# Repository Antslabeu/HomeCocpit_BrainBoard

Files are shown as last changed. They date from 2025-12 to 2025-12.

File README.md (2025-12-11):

# BrainBoard – STM32G0 CAN-FD Base Board

BrainBoard is a small base board built around an STM32G0B1KET6 MCU and a CAN-FD transceiver.
It is intended as a “brain” for various cockpit / IO modules, providing 3V3 power, CAN-FD
communication and a common expansion interface.

Repo: https://github.com/Antslabeu/HomeCocpit_BrainBoard  

> **Status:** prototype / WIP – use at your own risk.

---

## Main Features

- MCU: **STM32G0B1KET6**
  - CAN-FD, SPI, I²C, UART, timers/PWM, ADC, GPIO exposed on board connectors
- CAN-FD transceiver: **MCP2542FDxMF**
- Power architecture:
  - Input: **12 V**
  - On-board DC/DC step-down (2× **TPS62170DSG**):
    - **3.3 V / 1 A** rail for MCU and logic
    - **5 V** rail available on board
- PCB:
  - **4-layer** board, 1.6 mm
  - Stackup: **JLC04161H-7628** (JLCPCB)

---

## Programming Connector – `STM_PROG` (J1)

6-pin programming/debug connector for SWD + UART:

| Pin | Signal | Net | Description |
|-----|---|---|---|
| 1 | VCC | 3.3V | Target supply (3.3 V) |
| 2 | DIO | SW_DIO | SWD data I/O |
| 3 | RST | SW_RST | MCU reset (NRST) |
| 4 | CLK | SW_CLK | SWD clock |
| 5 | TX | SW_TX  | MCU UART TX (debug / bootloader)|
| 6 | GND | GND | Ground |

Compatible with ST-Link, J-Link and other SWD programmers.

---

## IO Connectors (Module Interface)

The board exposes module connectors that carry:

- **SPI bus** (shared)
- **4× chip select (CS) lines**
- **UART**
- **2× PWM outputs**
- **4× ADC inputs**
- **I²C bus** with **4.7 kΩ pull-ups** to 3.3 V
- **4× IO Board ID lines** – used to identify the type of module plugged into the connector  
  *(this Board ID mechanism is WIP and may change)*

Exact pinout is defined in the KiCad schematics (`connectors.kicad_sch`).

---

## CAN-FD Bus

- Transceiver: **MCP2542FDxMF** (CAN 2.0 / CAN FD up to 8 Mbit/s).
- CANH / CANL (and GND / power, if needed) are routed to dedicated connectors.
- Standard **120 Ω termination** is intended **only at the ends of the main bus**
  (check schematic for jumpers / solder bridges).

---

## Power

- **Input:** nominal **12 V**
- **Converters:** 2× **TPS62170DSG** buck regulators  
  (3 V–17 V in, up to 0.5 A each)  [Texas Instruments](https://www.ti.com/lit/ds/symlink/tps62170.pdf?utm_source=chatgpt.com)
- **Outputs:**
  - 12 V → **3.3 V / 1 A**
  - 12 V → **5 V** (aux rail)

### Typical consumption (board only, no external loads – rough estimate)

- STM32G0B1 in Run mode @ 64 MHz: typ. ~8–9 mA @ 3.3 V  [STMicroelectronics](https://www.st.com/resource/en/datasheet/stm32g0b1cc.pdf?utm_source=chatgpt.com)
- MCP2542FD supply current:
  - recessive: typ. ~2.5–5 mA @ 5 V
  - dominant: typ. ~55–70 mA @ 5 V  [DigiKey](https://www.digikey.kr/htmldatasheets/production/1897584/0/0/1/mcp2542-44fd-wfd.html?utm_source=chatgpt.com)
- TPS62170 quiescent current: ~17 µA from VIN each  [Texas Instruments](https://www.ti.com/lit/ds/symlink/tps62170.pdf?utm_source=chatgpt.com)

So, approximately:

- **Idle bus (recessive):**  
  - P_out ≈ 30 mW (MCU) + 25 mW (CAN) ≈ 55 mW  
  - With ~85% efficiency, input power ≈ 65 mW → **I_in ≈ 5–6 mA @ 12 V**
- **Worst-case dominant transmit:**  
  - P_out ≈ 30 mW (MCU) + 350 mW (CAN) ≈ 380 mW  
  - Input ≈ 450 mW → **I_in ≈ 35–40 mA @ 12 V**

Real current will be higher once external modules load 3.3 V rail.

Always respect absolute maximum ratings from datasheets.

---

## Files and Tools

All hardware files are in the repo root:

- `BrainBoard.kicad_pro` – main KiCad 8 project
- `BrainBoard.kicad_sch` + hierarchical sheets:
  - `power.kicad_sch`
  - `mcu.kicad_sch`
  - `can.kicad_sch`
  - `connectors.kicad_sch`
- `BrainBoard.kicad_pcb` – PCB layout (4-layer, JLC04161H-7628)
- `BrainBoard.pdf` – schematic PDF
- `LICENSE` – MIT

**CAD tool:** KiCad **8.x** (designed with 8.0.4).

---

## Getting Started (Hardware)

1. **Open the project**  
   Clone the repo and open `BrainBoard.kicad_pro` in KiCad 8.x.

2. **Review schematics and layout**  
   Check power, CAN and connector pinouts before manufacturing.

3. **Manufacturing**  
   - Generate Gerbers from KiCad.
   - Use the **JLC04161H-7628** 4-layer stackup if ordering from JLCPCB.

4. **First power-up**  
   - Apply **12 V** to the main power input.  
   - Verify 3.3 V and 5 V rails on test points.  
   - Connect a SWD programmer to **STM_PROG** and flash a simple test firmware
     (blink + CAN init).

5. **Integrate into CAN-FD network**  
   - Connect CANH/CANL to your main CAN-FD backbone.  
   - Enable 120 Ω termination only on physical bus ends.

---

## Firmware / Software

Firmware, examples and Board ID handling are **WIP** and not yet part of this repository.

Planned:

- Reference firmware for:
  - CAN-FD communication
  - SPI-based module control
  - Board ID-based module detection

---

## License

This hardware design is released under the **MIT License**  
(see the `LICENSE` file in the repository).

---

## Disclaimer

This is a prototype board.  
No guarantees are given – **use at your own risk**, especially in any safety-critical context.

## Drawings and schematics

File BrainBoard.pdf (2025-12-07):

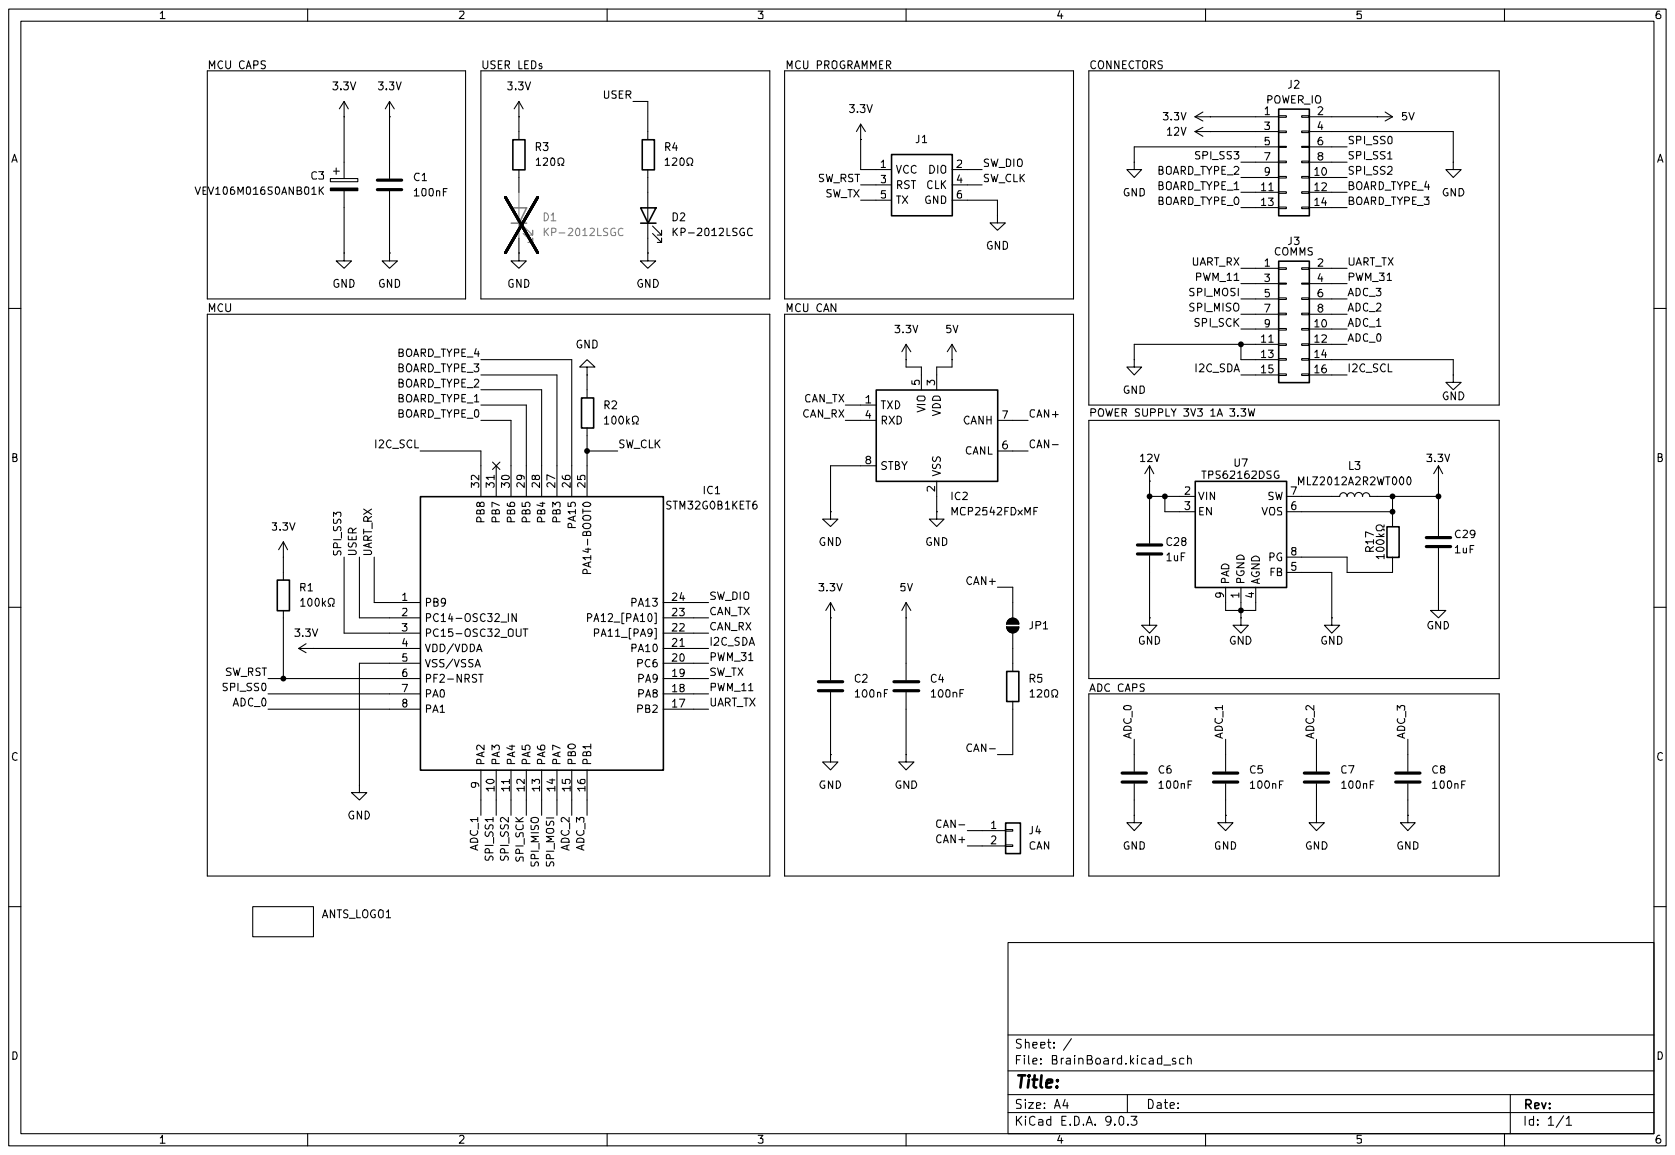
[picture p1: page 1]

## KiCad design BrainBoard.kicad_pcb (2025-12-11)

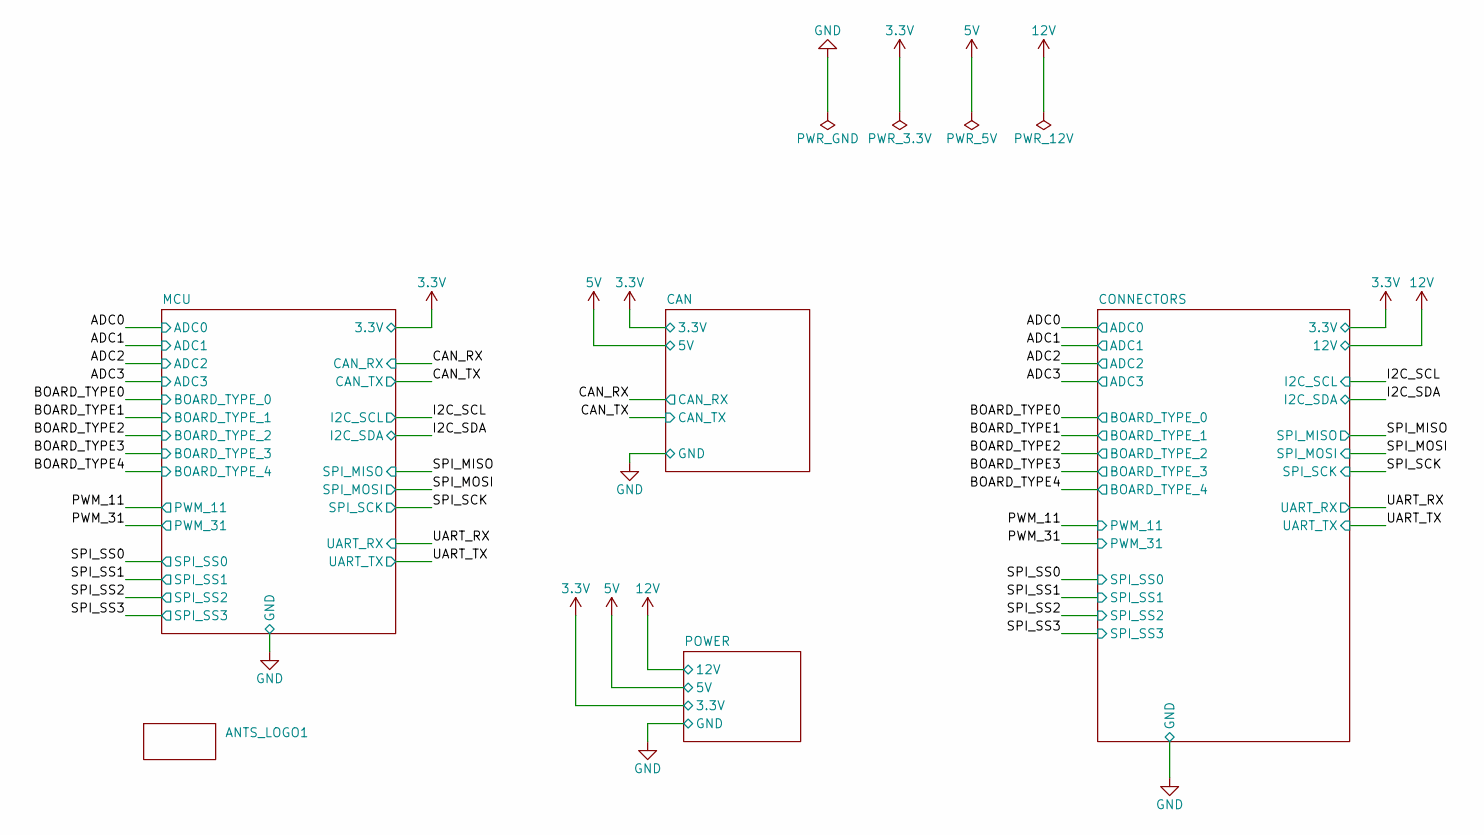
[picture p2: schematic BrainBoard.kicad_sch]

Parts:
ANTS_LOGO1: LOGO_H4

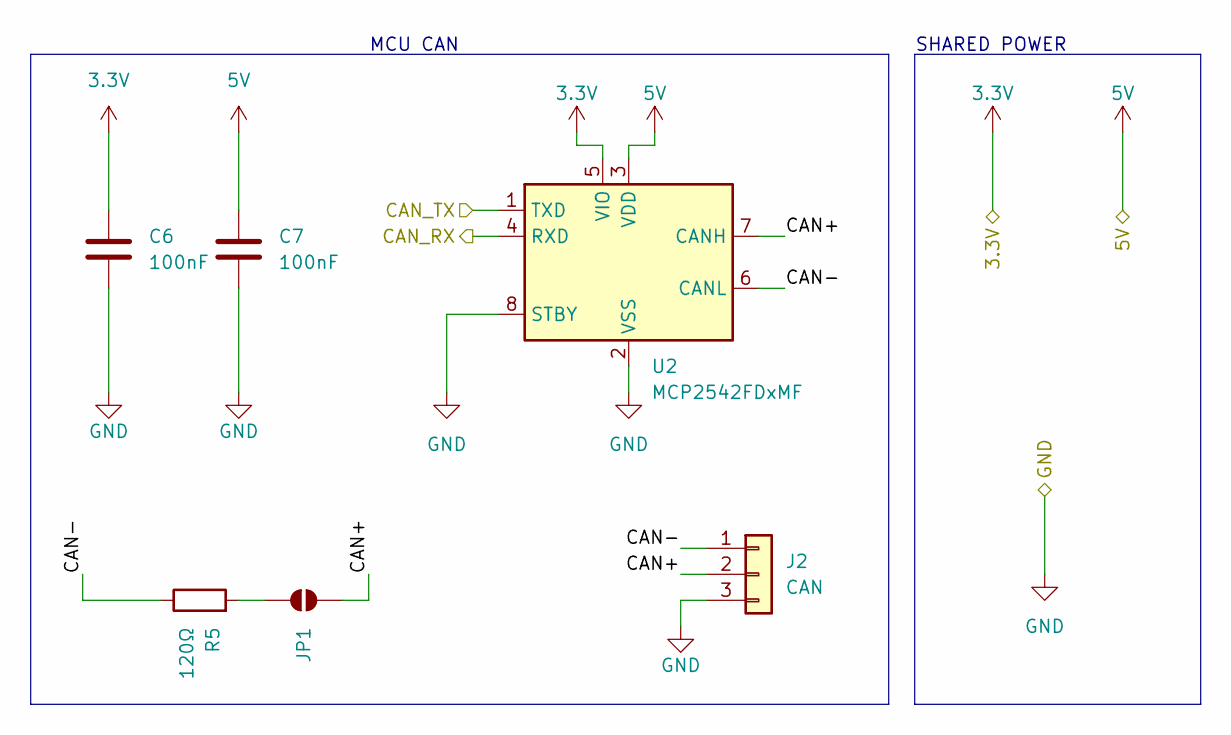
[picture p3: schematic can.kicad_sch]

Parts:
C6, C7: 100nF; C_0805_2012Metric
J2: CAN; JST_GH_BM03B-GHS-TBT_1x03-1MP_P1.25mm_Vertical
JP1: SolderJumper_2_Open; SolderJumper-2_P1.3mm_Open_RoundedPad1.0x1.5mm
R5: 120Ω; R_0805_2012Metric
U2: MCP2542FDxMF; SOIC-8_NO_PAD

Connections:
3.3V: C6.1, U2.5 (VIO); also elsewhere on the board
5V: C7.1, U2.3 (VDD); also elsewhere on the board
/CAN/CAN+: J2.2, JP1.2 (B), U2.7 (CANH)
/CAN/CAN-: J2.1, R5.1, U2.6 (CANL)
/CAN_RX: U2.4 (RXD); also elsewhere on the board
/CAN_TX: U2.1 (TXD); also elsewhere on the board
GND: C6.2, C7.2, J2.3, U2.2 (VSS), U2.8 (STBY); also elsewhere on the board
unnamed: JP1.1 (A), R5.2

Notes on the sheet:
SHARED POWER
MCU CAN

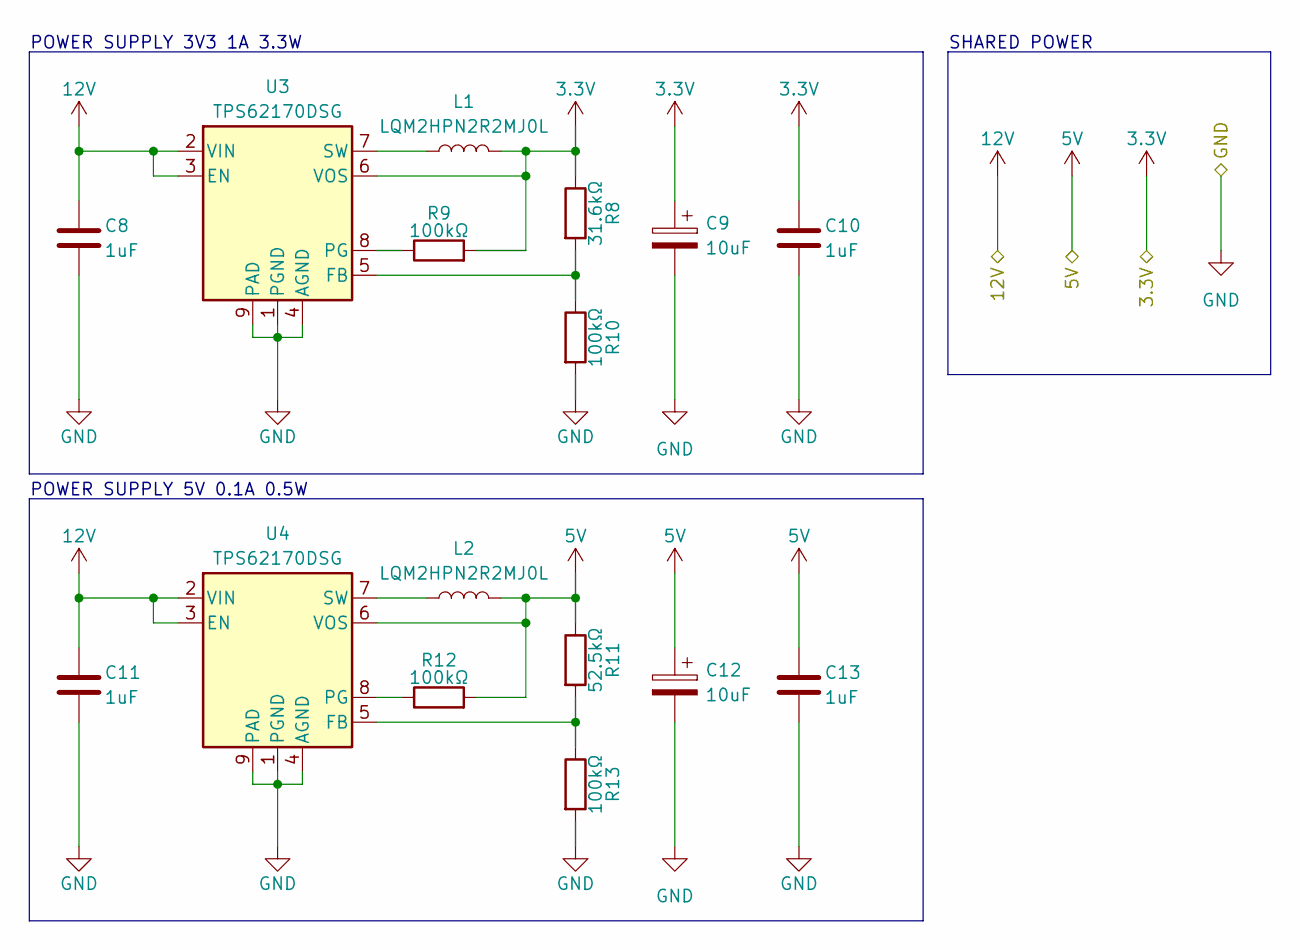
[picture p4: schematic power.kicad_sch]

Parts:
C8, C10, C11, C13: 1uF; C_0805_2012Metric
C9, C12: 10uF; CP_Elec_4x5.4
L1, L2: LQM2HPN2R2MJ0L; L_1008_2520Metric
R8: 31.6kΩ; R_0805_2012Metric
R9, R10, R12, R13: 100kΩ; R_0805_2012Metric
R11: 52.5kΩ; R_0805_2012Metric
U3, U4: TPS62170DSG; WSON-8-1EP_2x2mm_P0.5mm_EP0.9x1.6mm

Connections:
3.3V: C9.1, C10.1, L1.2, R8.1, R9.2, U3.6 (VOS); also elsewhere on the board
5V: C12.1, C13.1, L2.2, R11.1, R12.2, U4.6 (VOS); also elsewhere on the board
12V: C8.1, C11.1, U3.2 (VIN), U3.3 (EN), U4.2 (VIN), U4.3 (EN); also elsewhere on the board
GND: C8.2, C9.2, C10.2, C11.2, C12.2, C13.2, R10.2, R13.2, U3.1 (PGND), U3.4 (AGND), U3.9 (PAD), U4.1 (PGND), U4.4 (AGND), U4.9 (PAD); also elsewhere on the board
unnamed: R8.2, R10.1, U3.5 (FB)
unnamed: R9.1, U3.8 (PG)
unnamed: L1.1, U3.7 (SW)
unnamed: R11.2, R13.1, U4.5 (FB)
unnamed: R12.1, U4.8 (PG)
unnamed: L2.1, U4.7 (SW)

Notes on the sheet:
SHARED POWER
POWER SUPPLY 5V 0.1A 0.5W
POWER SUPPLY 3V3 1A 3.3W

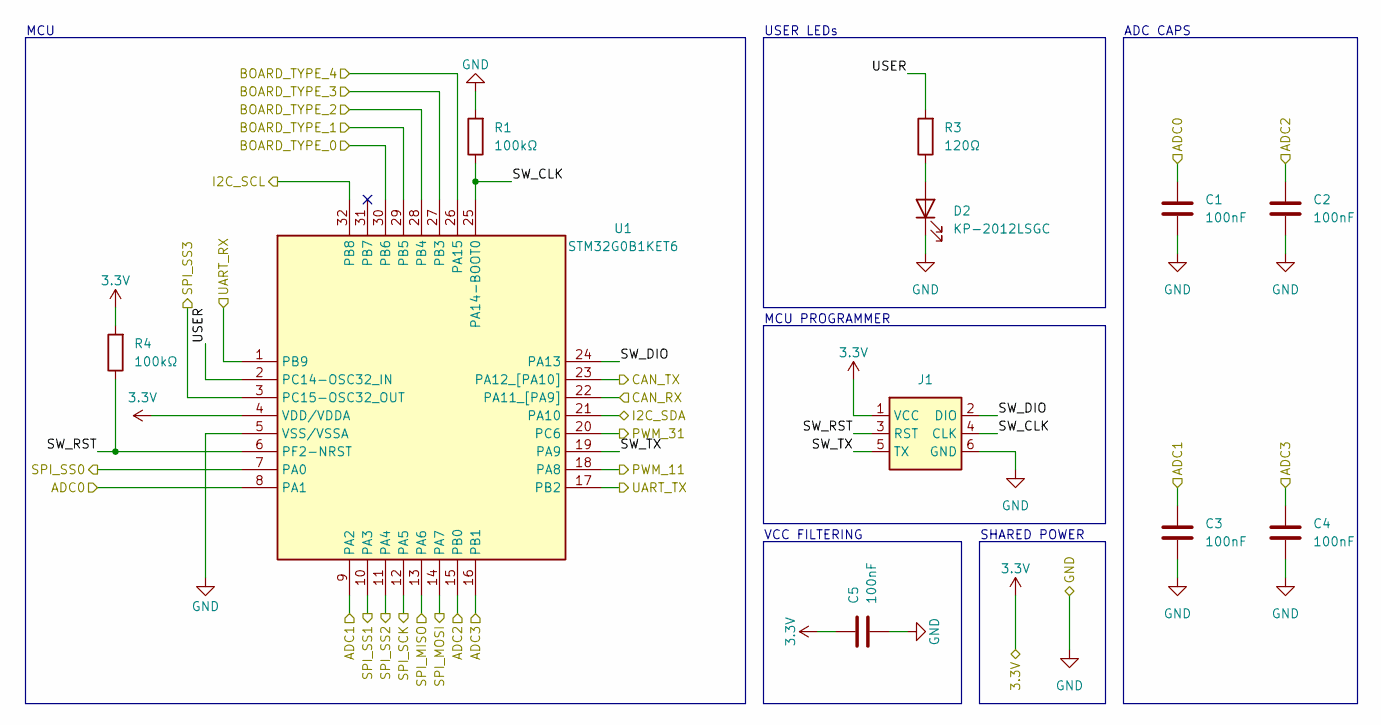
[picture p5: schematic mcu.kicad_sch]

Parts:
C1, C2, C3, C4, C5: 100nF; C_0805_2012Metric
D2: KP-2012LSGC; LED_0805_2012Metric
J1: PinSocket_2x03_P2.54mm_Vertical
R1, R4: 100kΩ; R_0805_2012Metric
R3: 120Ω; R_0805_2012Metric
U1: STM32G0B1KET6; LQFP-32_7x7mm_P0.8mm; Manufacturer_Part_Number STM32G0B1KET6

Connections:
3.3V: C5.1, J1.1 (VCC), R4.2, U1.4 (VDD/VDDA); also elsewhere on the board
/ADC0: C1.1, U1.8 (PA1); also elsewhere on the board
/ADC1: C3.1, U1.9 (PA2); also elsewhere on the board
/ADC2: C2.1, U1.15 (PB0); also elsewhere on the board
/ADC3: C4.1, U1.16 (PB1); also elsewhere on the board
/BOARD_TYPE0: U1.30 (PB6); also elsewhere on the board
/BOARD_TYPE1: U1.29 (PB5); also elsewhere on the board
/BOARD_TYPE2: U1.28 (PB4); also elsewhere on the board
/BOARD_TYPE3: U1.27 (PB3); also elsewhere on the board
/BOARD_TYPE4: U1.26 (PA15); also elsewhere on the board
/CAN_RX: U1.22 (PA11_[PA9]); also elsewhere on the board
/CAN_TX: U1.23 (PA12_[PA10]); also elsewhere on the board
/I2C_SCL: U1.32 (PB8); also elsewhere on the board
/I2C_SDA: U1.21 (PA10); also elsewhere on the board
/MCU/SW_CLK: J1.4 (CLK), R1.1, U1.25 (PA14-BOOT0)
/MCU/SW_DIO: J1.2 (DIO), U1.24 (PA13)
/MCU/SW_RST: J1.3 (RST), R4.1, U1.6 (PF2-NRST)
/MCU/SW_TX: J1.5 (TX), U1.19 (PA9)
/MCU/USER: R3.2, U1.2 (PC14-OSC32_IN)
/PWM_11: U1.18 (PA8); also elsewhere on the board
/PWM_31: U1.20 (PC6); also elsewhere on the board
/SPI_MISO: U1.13 (PA6); also elsewhere on the board
/SPI_MOSI: U1.14 (PA7); also elsewhere on the board
/SPI_SCK: U1.12 (PA5); also elsewhere on the board
/SPI_SS0: U1.7 (PA0); also elsewhere on the board
/SPI_SS1: U1.10 (PA3); also elsewhere on the board
/SPI_SS2: U1.11 (PA4); also elsewhere on the board
/SPI_SS3: U1.3 (PC15-OSC32_OUT); also elsewhere on the board
/UART_RX: U1.1 (PB9); also elsewhere on the board
/UART_TX: U1.17 (PB2); also elsewhere on the board
GND: C1.2, C2.2, C3.2, C4.2, C5.2, D2.1 (K), J1.6 (GND), R1.2, U1.5 (VSS/VSSA); also elsewhere on the board
unnamed: D2.2 (A), R3.1

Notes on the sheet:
SHARED POWER
VCC FILTERING
MCU
MCU PROGRAMMER
ADC CAPS
USER LEDs

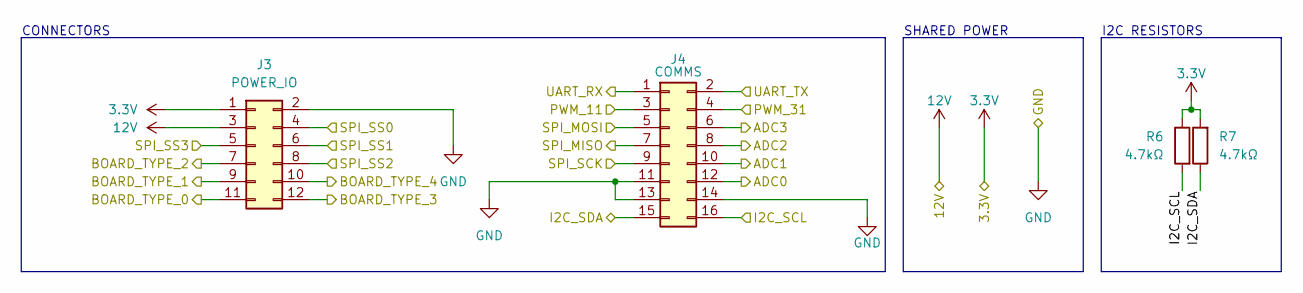
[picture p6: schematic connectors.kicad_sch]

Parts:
J3: POWER_IO; PinHeader_2x06_P2.54mm_Vertical
J4: COMMS; PinHeader_2x08_P2.54mm_Vertical
R6, R7: 4.7kΩ; R_0805_2012Metric

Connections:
3.3V: J3.1, R6.1, R7.2; also elsewhere on the board
12V: J3.3; also elsewhere on the board
/ADC0: J4.12; also elsewhere on the board
/ADC1: J4.10; also elsewhere on the board
/ADC2: J4.8; also elsewhere on the board
/ADC3: J4.6; also elsewhere on the board
/BOARD_TYPE0: J3.11; also elsewhere on the board
/BOARD_TYPE1: J3.9; also elsewhere on the board
/BOARD_TYPE2: J3.7; also elsewhere on the board
/BOARD_TYPE3: J3.12; also elsewhere on the board
/BOARD_TYPE4: J3.10; also elsewhere on the board
/I2C_SCL: J4.16, R6.2; also elsewhere on the board
/I2C_SDA: J4.15, R7.1; also elsewhere on the board
/PWM_11: J4.3; also elsewhere on the board
/PWM_31: J4.4; also elsewhere on the board
/SPI_MISO: J4.7; also elsewhere on the board
/SPI_MOSI: J4.5; also elsewhere on the board
/SPI_SCK: J4.9; also elsewhere on the board
/SPI_SS0: J3.4; also elsewhere on the board
/SPI_SS1: J3.6; also elsewhere on the board
/SPI_SS2: J3.8; also elsewhere on the board
/SPI_SS3: J3.5; also elsewhere on the board
/UART_RX: J4.1; also elsewhere on the board
/UART_TX: J4.2; also elsewhere on the board
GND: J3.2, J4.11, J4.13, J4.14; also elsewhere on the board

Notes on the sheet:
SHARED POWER
I2C RESISTORS
CONNECTORS

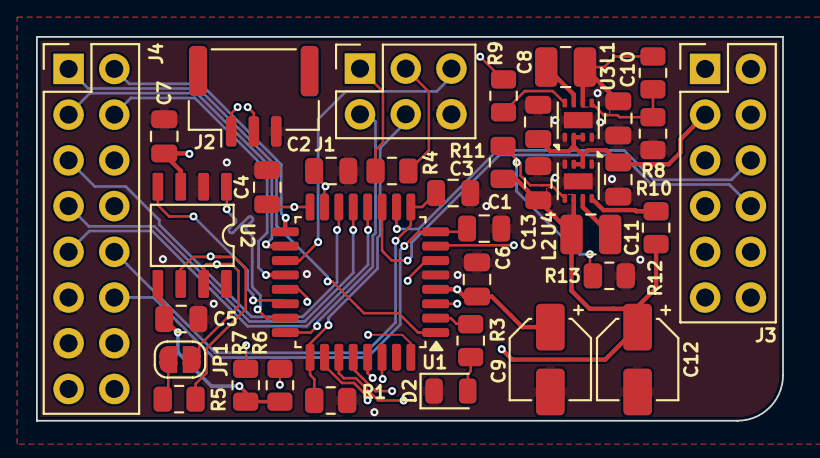
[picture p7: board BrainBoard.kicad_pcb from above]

Board: 4 copper layers, 41.4 x 21.3 mm, 38 parts (1 on the bottom side), 43 nets.

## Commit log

2025-12-07 Initial commit
    Initial commit - added functions
    [BrainBoard.kicad_pcb, BrainBoard.kicad_sch]
2025-12-07 Changed CAN port to 3pin;
    [BrainBoard.kicad_pcb, BrainBoard.kicad_sch]
2025-12-11 Schematic overhaul: Added separated sheets for functions, Added 5V DCDC, Board overhaul: Modified to be MFR ready, Added 5V DCDC,
    [BrainBoard.kicad_pcb, BrainBoard.kicad_sch, can.kicad_sch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]
2025-12-11 Add README
    Added detailed documentation for the BrainBoard, including features, connectors, power specifications, and getting started instructions.
